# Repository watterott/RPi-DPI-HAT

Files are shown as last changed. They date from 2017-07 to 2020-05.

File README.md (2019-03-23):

# RPi-DPI-HAT
Raspberry Pi HAT (Hardware Attached on Top) for TFT-Displays with DPI (Display Parallel Interface).

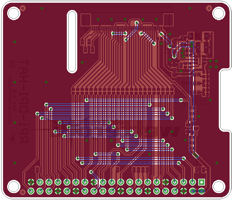
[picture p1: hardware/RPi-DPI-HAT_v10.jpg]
RPi-DPI-HAT


* 40pin connector for TFT-Display
* LED Backlight Boost Regulator (up to 35V)
* Single 5V Power Supply via GPIO connector
* Open-Source and released under the [Creative Commons Attribution Share-Alike License](https://creativecommons.org/licenses/by-sa/4.0/).
* **[Documentation on learn.watterott.com](https://learn.watterott.com)**

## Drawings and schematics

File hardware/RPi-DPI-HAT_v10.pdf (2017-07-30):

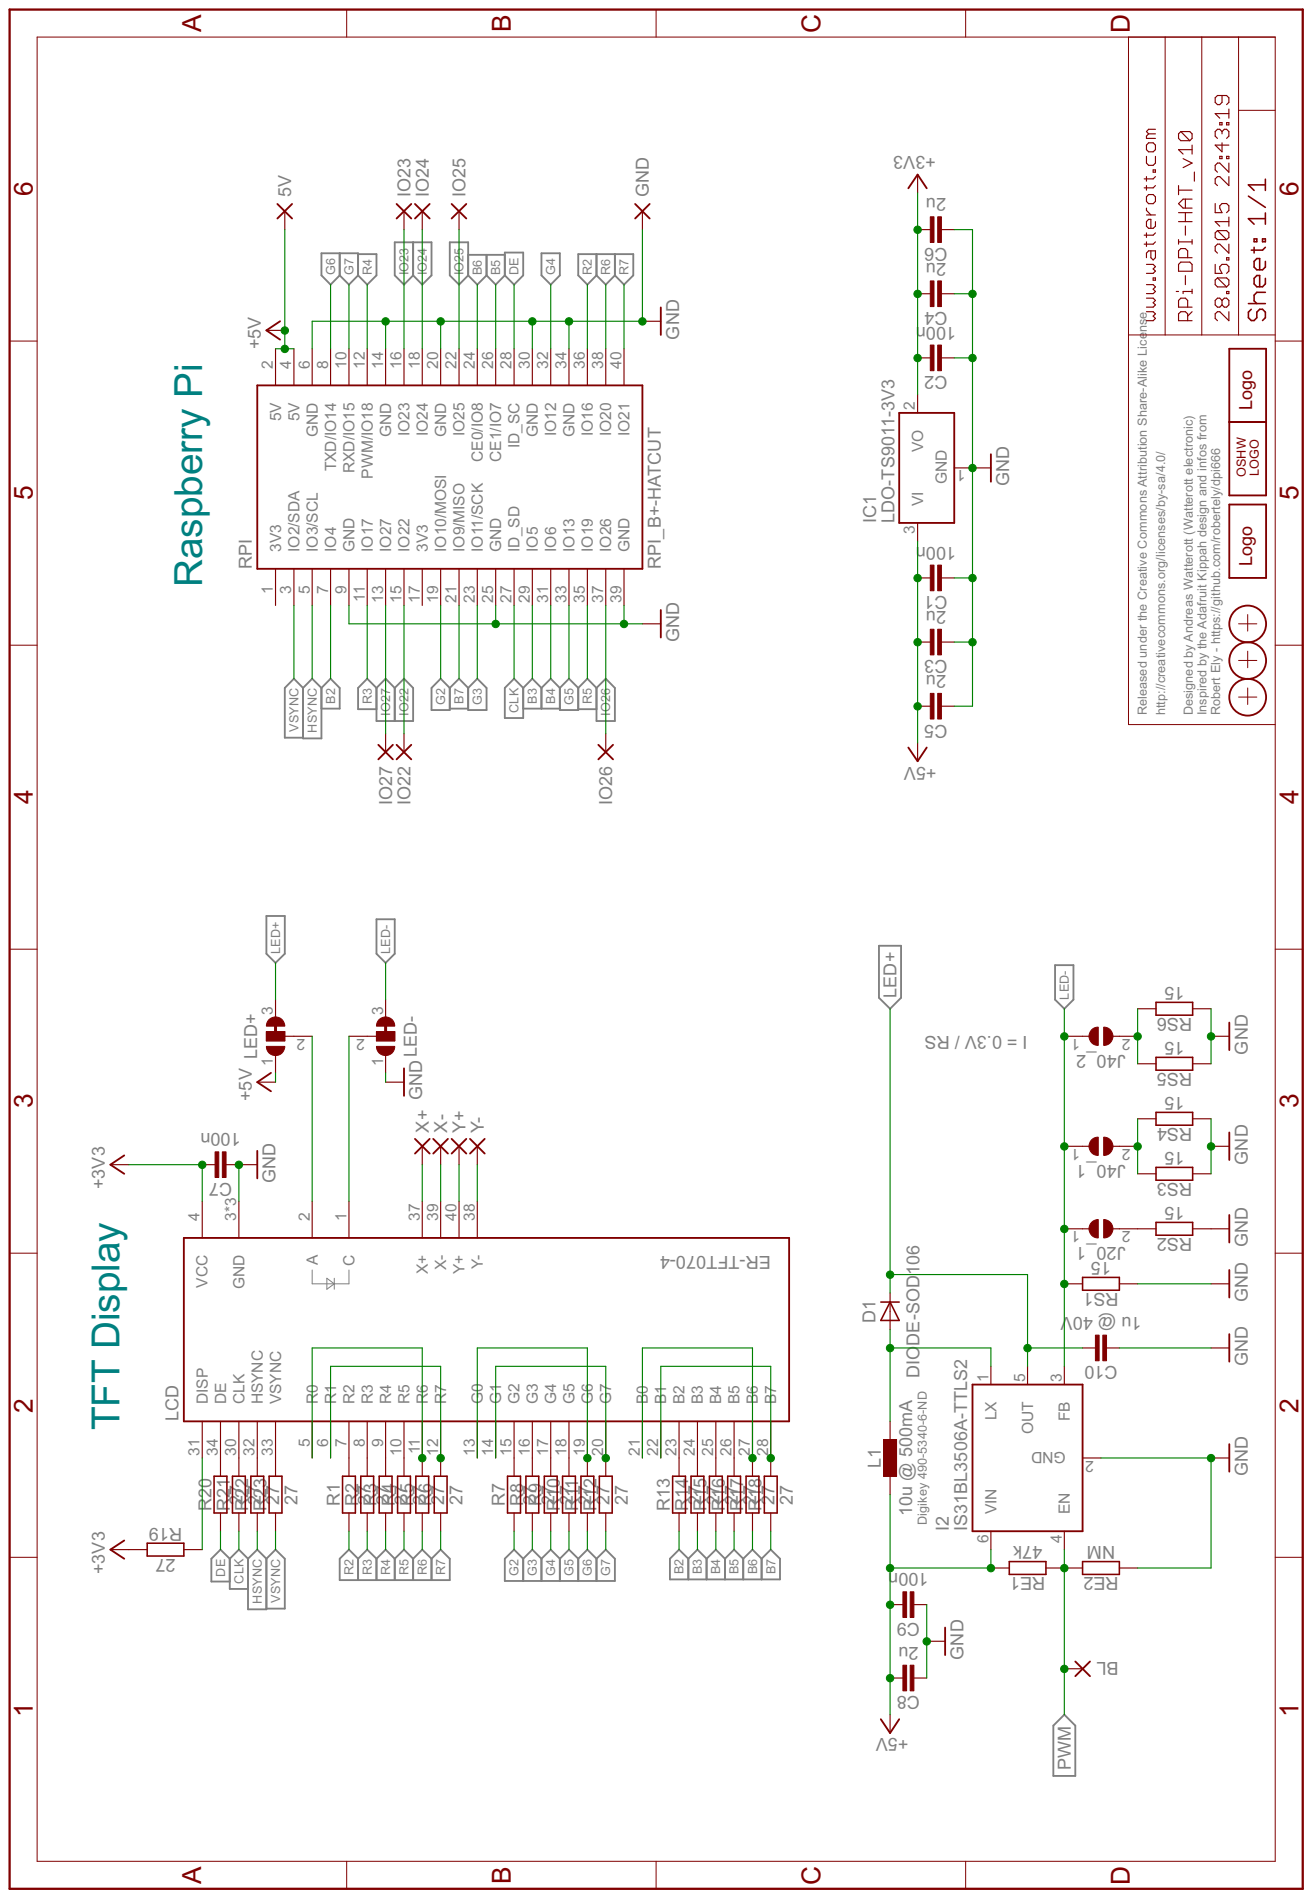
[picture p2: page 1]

Released under the Creative Commons Attribution Share-Alike License

http://creativecommons.org/licenses/by-sa/4.0/ Designed by Andreas Watterott (Watterott electronic)

Inspired by the Adafruit Kippah design and infos from

Robert Ely - https://github.com/robertely/dpi666

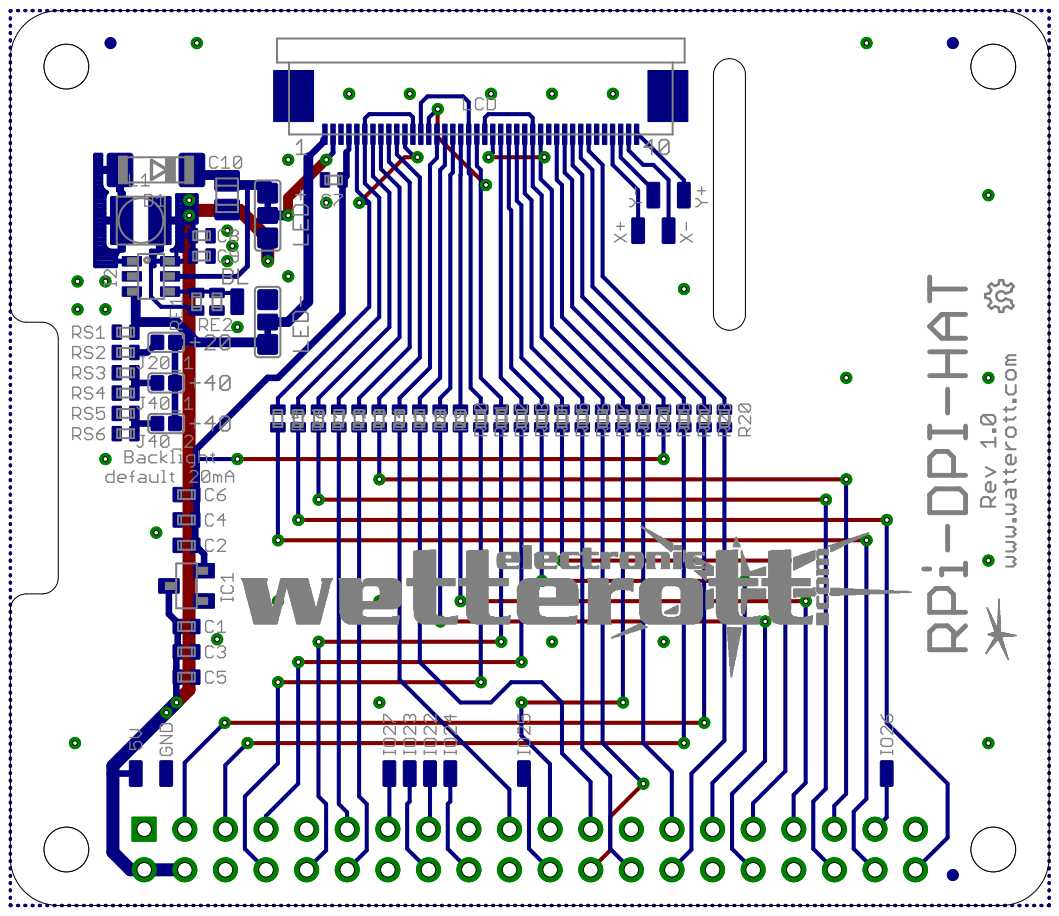
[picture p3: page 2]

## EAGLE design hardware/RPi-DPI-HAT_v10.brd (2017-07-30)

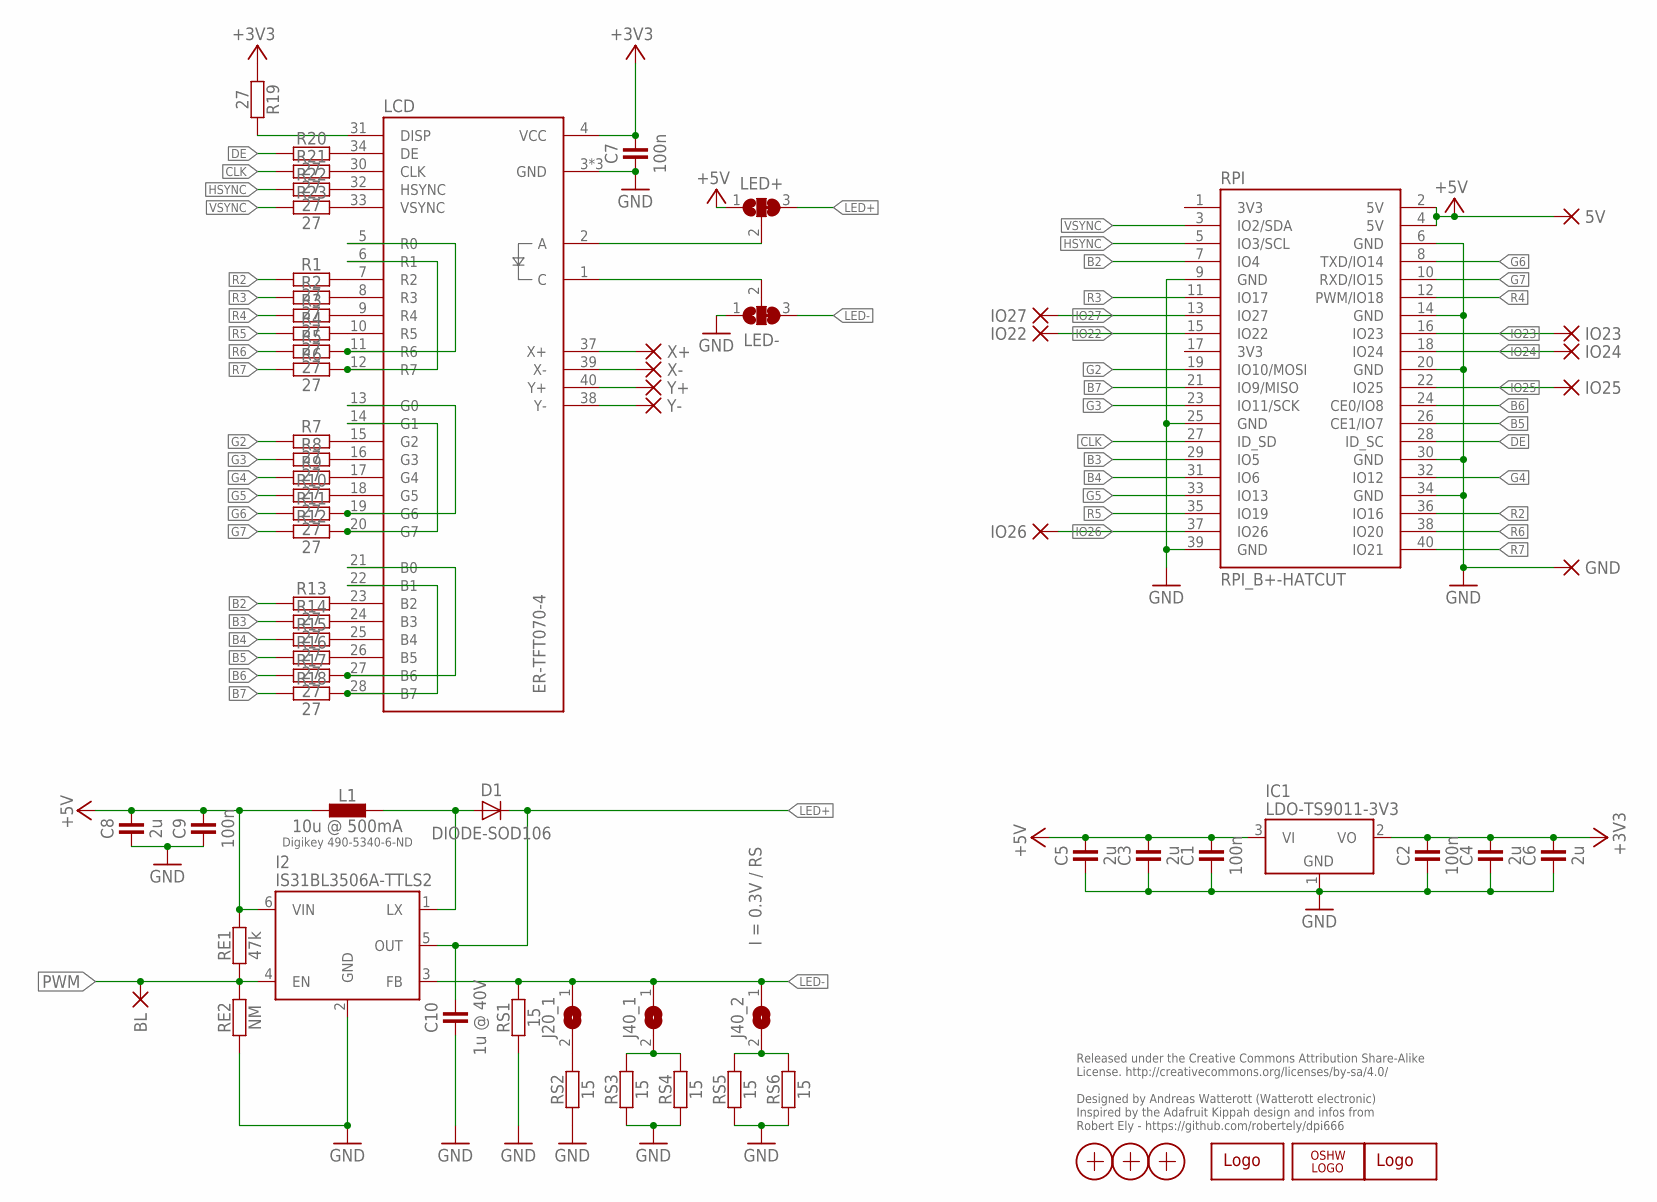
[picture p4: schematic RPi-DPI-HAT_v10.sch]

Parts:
5V: PAD-0.80X1.60_NC
BL: PAD-0.80X1.60_NC
C1, C2, C7, C9: 100n; C0402
C3, C4, C5, C6, C8: 2u; C0402
C10: 1u @ 40V; C0805
D1: DIODE-SOD106; SOD106
GND: PAD-0.80X1.60_NC
I2: IS31BL3506A-TTLS2; SOT23-6
IC1: LDO-TS9011-3V3; SOT23
IO22, IO23, IO24, IO25, IO26, IO27: PAD-0.80X1.60_NC
J20_1, J40_1, J40_2: JUMPER2-0402
L1: 10u @ 500mA; L_1212
LCD: ER-TFT070-4; FPC40
LED+: JUMPER3-0603-NC; JUMPER3-0603_NC
LED-: JUMPER3-0603-NC; JUMPER3-0603_NC
LOGO1: LOGO-S_PLACE_S; SPARK_TPLACE_S
LOGO2: OSHW_LOGOX0070; OSHW_6X70
LOGO3: LOGO-PLACE; LOGO_TPLACE
R1, R2, R3, R4, R5, R6, R7, R8, R9, R10, R11, R12, R13, R14, R15, R16, R17, R18, R19, R20, R21, R22, R23: 27; C0402
RE1: 47k; C0402
RE2: NM; C0402
RPI: RPI_B+-HATCUT; RPI-B+HAT_CUTOUT
RS1, RS2, RS3, RS4, RS5, RS6: 15; C0402
X1, X2, X3: PASSER-07; PASSER_07MM
X+: PAD-0.80X1.60_NC
X-: PAD-0.80X1.60_NC
Y+: PAD-0.80X1.60_NC
Y-: PAD-0.80X1.60_NC

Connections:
+3V3: C2.2, C4.2, C6.2, C7.2, IC1.2 (VO), LCD.4 (VCC), R19.1
+5V: 5V.1, C1.2, C3.2, C5.2, C8.2, C9.2, I2.6 (VIN), IC1.3 (VI), L1.1, LED+.1, RE1.2, RPI.2 (5V), RPI.4 (5V)
A: LCD.2 (A), LED+.2
B2: R13.1, RPI.7 (IO4)
B3: R14.1, RPI.29 (IO5)
B4: R15.1, RPI.31 (IO6)
B5: R16.1, RPI.26 (CE1/IO7)
B6: R17.1, RPI.24 (CE0/IO8)
B7: R18.1, RPI.21 (IO9/MISO)
C: LCD.1 (C), LED-.2
CLK: R21.1, RPI.27 (ID_SD)
DE: R20.1, RPI.28 (ID_SC)
G2: R7.1, RPI.19 (IO10/MOSI)
G3: R8.1, RPI.23 (IO11/SCK)
G4: R9.1, RPI.32 (IO12)
G5: R10.1, RPI.33 (IO13)
G6: R11.1, RPI.8 (TXD/IO14)
G7: R12.1, RPI.10 (RXD/IO15)
GND: C1.1, C2.1, C3.1, C4.1, C5.1, C6.1, C7.1, C8.1, C9.1, C10.1, GND.1, I2.2 (GND), IC1.1 (GND), LCD.3 (GND), LCD.29 (GND), LCD.36 (GND), LED-.1, RE2.1, RPI.6 (GND), RPI.9 (GND), RPI.14 (GND), RPI.20 (GND), RPI.25 (GND), RPI.30 (GND), RPI.34 (GND), RPI.39 (GND), RS1.1, RS2.1, RS3.1, RS4.1, RS5.1, RS6.1
HSYNC: R22.1, RPI.5 (IO3/SCL)
IO22: IO22.1, RPI.15 (IO22)
IO23: IO23.1, RPI.16 (IO23)
IO24: IO24.1, RPI.18 (IO24)
IO25: IO25.1, RPI.22 (IO25)
IO26: IO26.1, RPI.37 (IO26)
IO27: IO27.1, RPI.13 (IO27)
LED+: C10.2, D1.C, I2.5 (OUT), LED+.3
LED-: I2.3 (FB), J20_1.1, J40_1.1, J40_2.1, LED-.3, RS1.2
LX: D1.A, I2.1 (LX), L1.2
unnamed: J40_1.2, RS3.2, RS4.2
unnamed: J20_1.2, RS2.2
unnamed: LCD.7 (R2), R1.2
unnamed: LCD.5 (R0), LCD.11 (R6), R5.2
unnamed: J40_2.2, RS5.2, RS6.2
unnamed: LCD.6 (R1), LCD.12 (R7), R6.2
unnamed: LCD.8 (R3), R2.2
unnamed: LCD.9 (R4), R3.2
unnamed: LCD.10 (R5), R4.2
unnamed: LCD.15 (G2), R7.2
unnamed: LCD.16 (G3), R8.2
unnamed: LCD.17 (G4), R9.2
unnamed: LCD.18 (G5), R10.2
unnamed: LCD.13 (G0), LCD.19 (G6), R11.2
unnamed: LCD.14 (G1), LCD.20 (G7), R12.2
unnamed: LCD.23 (B2), R13.2
unnamed: LCD.24 (B3), R14.2
unnamed: LCD.25 (B4), R15.2
unnamed: LCD.26 (B5), R16.2
unnamed: LCD.21 (B0), LCD.27 (B6), R17.2
unnamed: LCD.22 (B1), LCD.28 (B7), R18.2
unnamed: LCD.31 (DISP), R19.2
unnamed: LCD.34 (DE), R20.2
unnamed: LCD.30 (CLK), R21.2
unnamed: LCD.32 (HSYNC), R22.2
unnamed: LCD.33 (VSYNC), R23.2
PWM: BL.1, I2.4 (EN), RE1.1, RE2.2
R2: R1.1, RPI.36 (IO16)
R3: R2.1, RPI.11 (IO17)
R4: R3.1, RPI.12 (PWM/IO18)
R5: R4.1, RPI.35 (IO19)
R6: R5.1, RPI.38 (IO20)
R7: R6.1, RPI.40 (IO21)
VSYNC: R23.1, RPI.3 (IO2/SDA)
X+: LCD.37 (X+), X+.1
X-: LCD.39 (X-), X-.1
Y+: LCD.40 (Y+), Y+.1
Y-: LCD.38 (Y-), Y-.1

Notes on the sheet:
Released under the Creative Commons Attribution Share-Alike License. http://creativecommons.org/licenses/by-sa/4.0/ Designed by Andreas Watterott (Watterott electronic) Inspired by the Adafruit Kippah design and infos from Robert Ely - https://github.com/robertely/dpi666
I = 0.3V / RS
Digikey 490-5340-6-ND

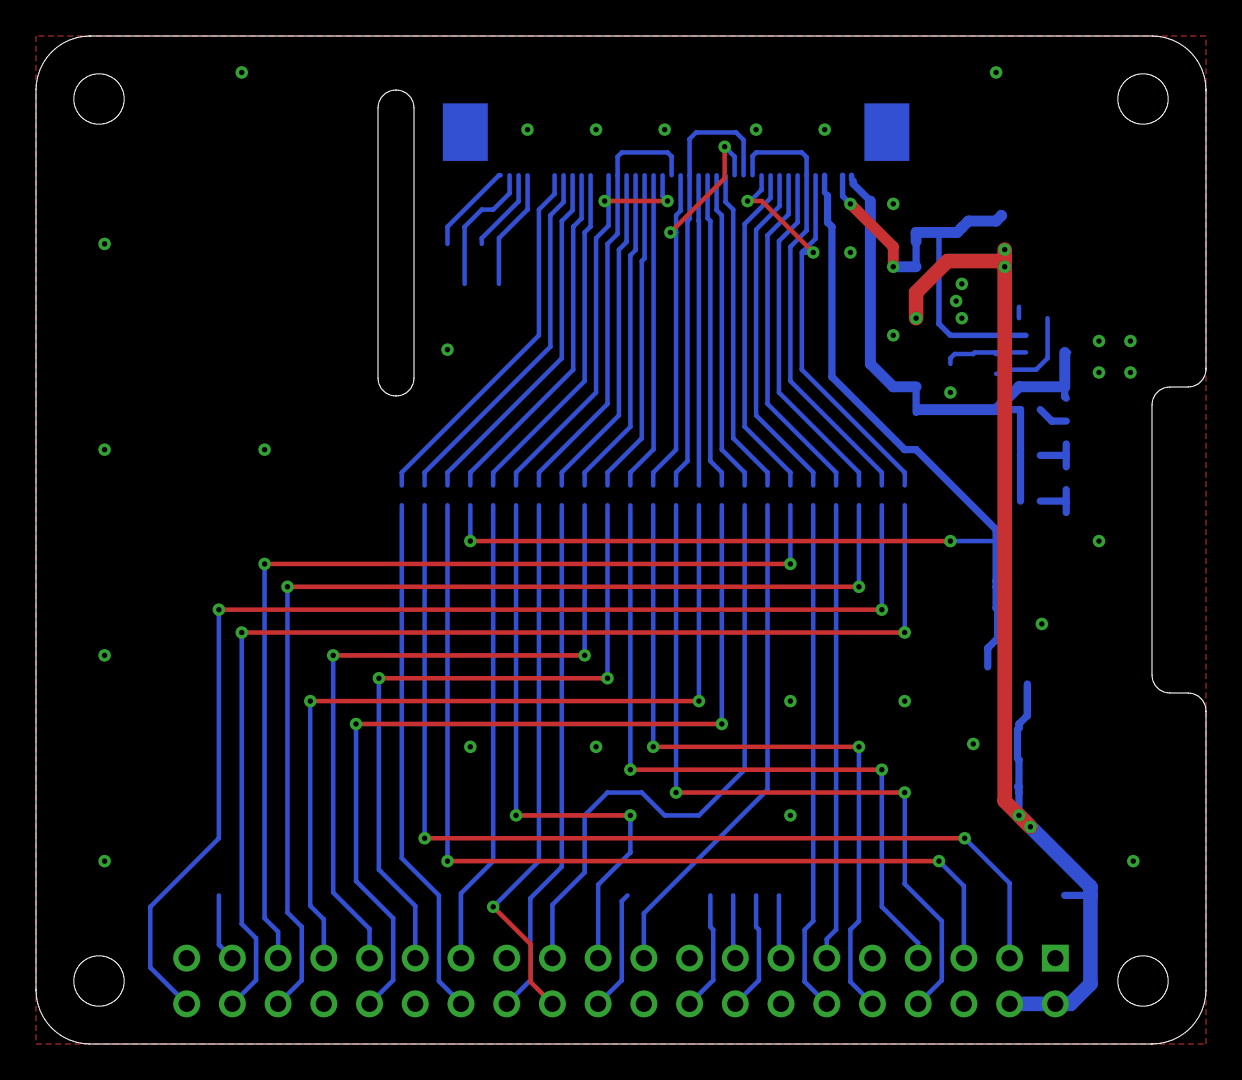
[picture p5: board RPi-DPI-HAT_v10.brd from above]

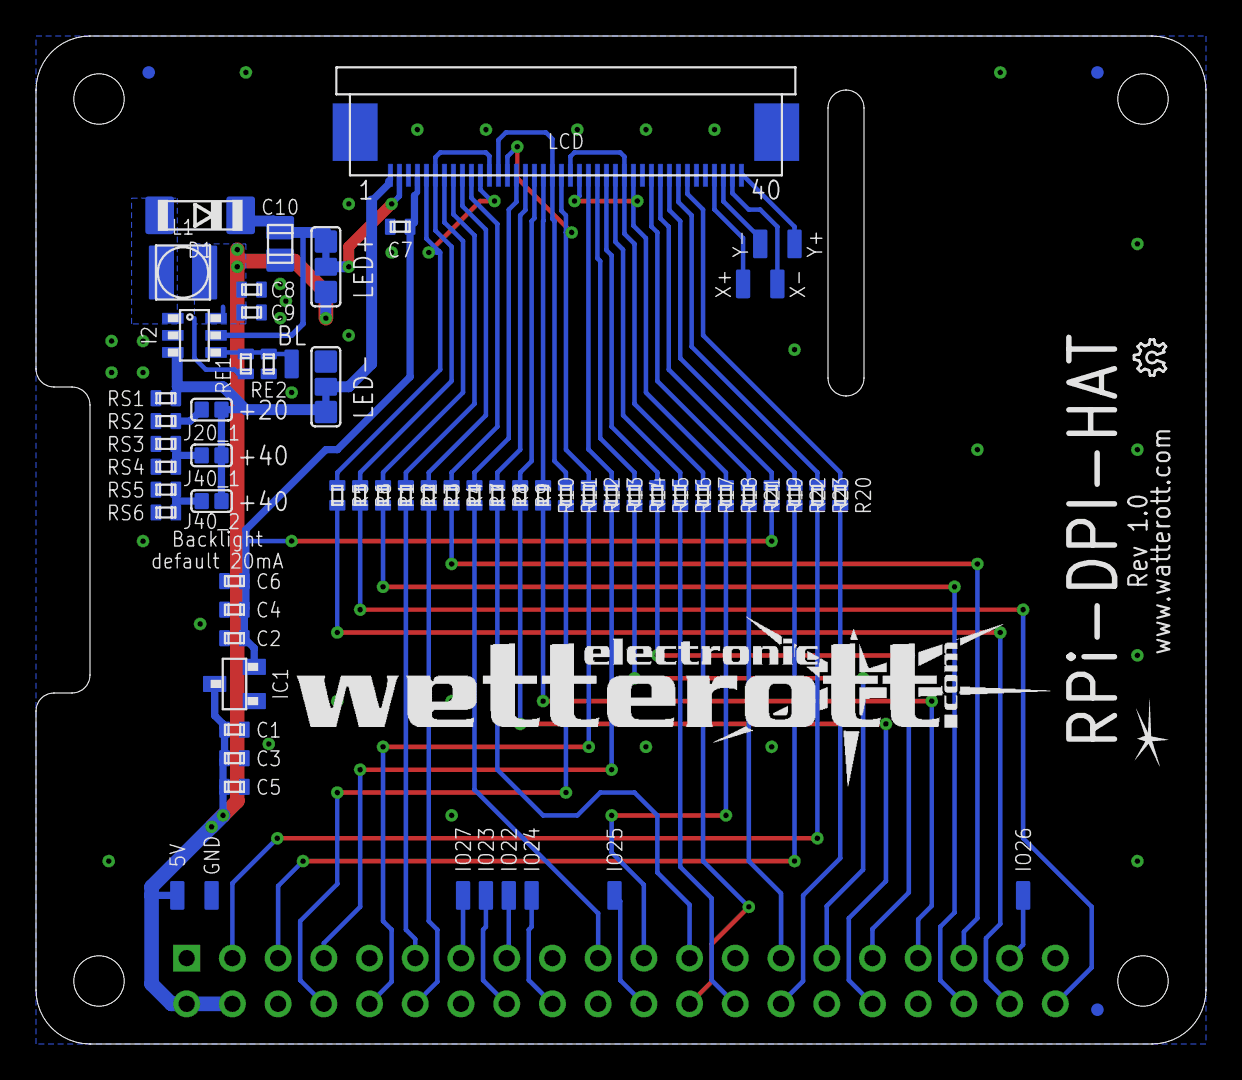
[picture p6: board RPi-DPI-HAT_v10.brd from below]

Board: 2 copper layers, 65.0 x 56.0 mm, 71 parts (70 on the bottom side), 67 nets.

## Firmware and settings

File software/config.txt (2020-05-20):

# Raspberry Pi Settings - /boot/config.txt
# http://elinux.org/RPiconfig
# https://github.com/robertely/dpi666 and http://blog.reasonablycorrect.com/raw-dpi-raspberry-pi/
# hdmi_cvt=<width> <height> <framerate> <aspect> <margins> <interlaced> <reduced_blanking>
# hdmi_timing=<h_active_pixels> <h_sync_polarity> <h_front_porch> <h_sync_pulse> <h_back_porch> <v_active_lines> <v_sync_polarity> <v_front_porch> <v_sync_pulse> <v_back_porch> <v_sync_offset_a> <v_sync_offset_b> <pixel_rep> <framerate> <interlaced> <pixel_freq> <aspect>
# aspect ratio: 1=4:3, 2=14:9, 3=16:9, 4=5:4, 5=16:10, 6=15:9, 7=21:9, 8=64:27

# overscan to adjust image position (test with 0, -16, -32)
overscan_left=0
overscan_right=0
overscan_top=0
overscan_bottom=0

# disable SPI and I2C
dtparam=spi=off
dtparam=i2c_arm=off

# enable TFT Display
enable_dpi_lcd=1
display_default_lcd=1
dpi_group=2
dpi_mode=87

# uncomment for 480x272 display (TFT043-3)
#dpi_output_format=454661
#hdmi_timings=480 0 1 41 2 272 0 2 10 2 0 0 0 60 0 9009000 3

# uncomment for 800x480 display (TFT050-3, TFT070-4)
#dpi_output_format=454661
#hdmi_cvt=800 480 60 6 0 0 0
#can also be used: hdmi_timings=800 0 40 48 88 480 0 13 3 32 0 0 0 60 0 31000000 6

# uncomment for 800x480 display (Adafruit 5" from Robert Ely)
#dpi_output_format=458773
#hdmi_timings=800 1 0 48 0 480 0 13 3 32 0 0 0 60 0 23040000 6

# uncomment for 480x272 display (Adafruit 4.3")
#dpi_output_format=520197
#hdmi_timings=480 0 40 48 88 272 0 13 3 32 0 0 0 60 0 32000000 3

# 0 degrees - normal
#display_rotate=0
# 90 degrees
#display_rotate=1
# 180 degrees
#display_rotate=2
# 270 degrees
#display_rotate=3
# horizontal flip
#display_rotate=0x10000
# vertical flip
#display_rotate=0x20000

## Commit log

2018-02-03 moved files
    [config.txt]
2018-12-13 moved to FFC-Extender repo
    [FFC-Extender_v10.brd, FFC-Extender_v10.sch]
2020-05-20 updated config info
    [config.txt]
